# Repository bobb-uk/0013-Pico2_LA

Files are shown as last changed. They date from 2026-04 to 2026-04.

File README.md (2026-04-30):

# 0013-Pico2_LA
Logic analyser variant originally by El Gusman  https://github.com/gusmanb

Design errors:\
The M3 mounting holes have their PTH set at 3.0mm by mistake when it should be 3.2mm\
Pin1 on each of the three headers has it's solder mask opening a little too large.  It is possible to short the pin to GND when assembling.\
\
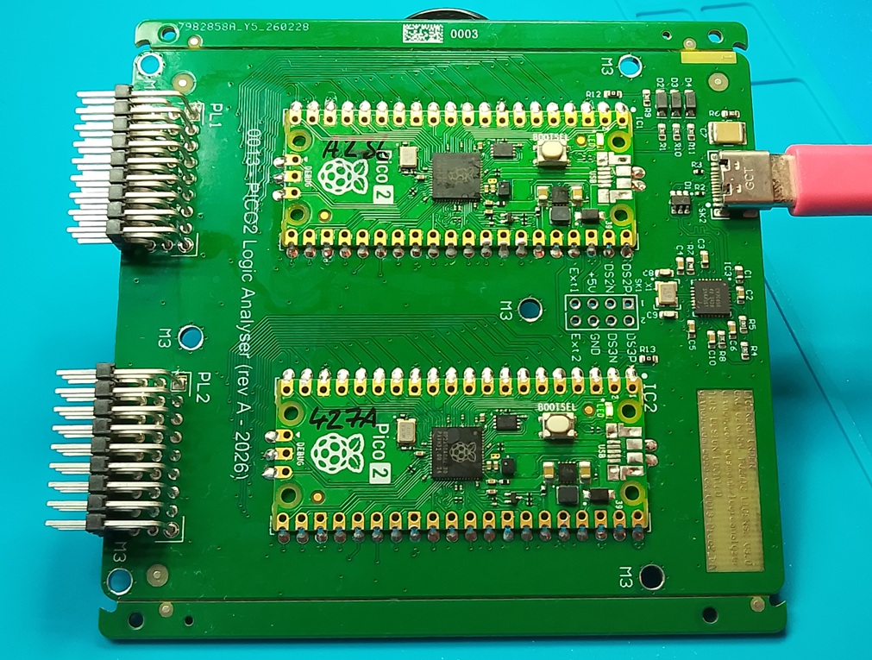
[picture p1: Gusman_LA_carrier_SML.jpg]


PL1 is the Master header.  PL2 is the 1st Slave header.

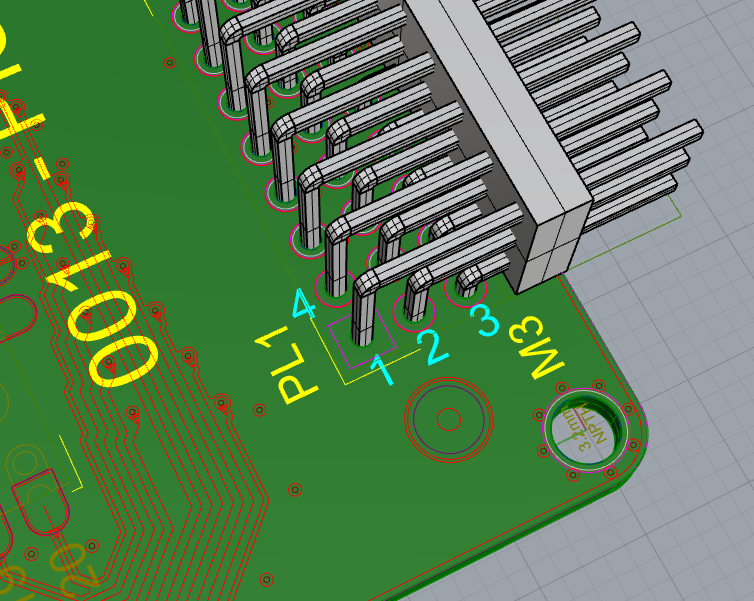
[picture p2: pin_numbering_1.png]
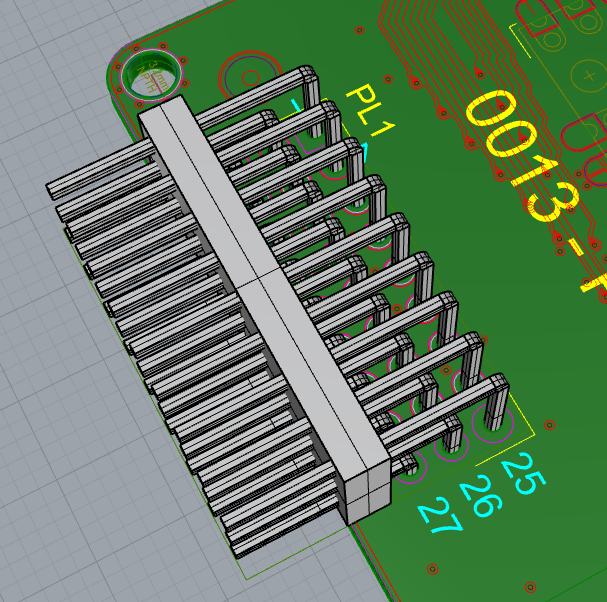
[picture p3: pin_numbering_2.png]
|  |  |
| --- | --- |
| When studying the schematic, make note of the pin numbering between the symbol and the footprint of PL1 & PL2. |

There will be a rev B of this design in the near future.\
The new revision will use programmable (with a capacitor) reset supervisor IC, so each of the PICO2 modules will have their nRESET inputs released in sequence upon power connected to the board.\
This will ensure the ttyACMx enumerations are in the sequence we want.\
Then we can assign ttyACM0 as the Master and ttyACM1 as the first Slave and know for certain that ttyACM0 references the Master pins on the signal headers.\
This saves having to use DMESG to look at which PICO2 was given which ttyACM port.

Head over to the Discussions tab if you want to make any comments.

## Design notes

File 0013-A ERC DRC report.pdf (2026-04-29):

## Electrical Rules Check Report

Class | Document | Message
Warning | Top.SchDoc | Nets Wire +5V has multiple names (Port +5V, Port VBUS, Power Object +5V (9), Power Object VBUS (3), Sheet Entry
| | PICO2-VBUS(Passive), Sheet Entry USB Hub-+5V(Passive))
Warning | Top.SchDoc | Nets Wire CHAN_0 has multiple names (Net Label CHAN_0 (4), Port CHANNELS.0 (2), Sheet Entry DIGITAL
| | IO-CHANNELS.0(Passive), Sheet Entry PICO2-CHANNELS.0(Passive))
Warning | Top.SchDoc | Nets Wire CHAN_1 has multiple names (Net Label CHAN_1 (4), Port CHANNELS.1 (2), Sheet Entry DIGITAL
| | IO-CHANNELS.1(Passive), Sheet Entry PICO2-CHANNELS.1(Passive))
Warning | Top.SchDoc | Nets Wire CHAN_2 has multiple names (Net Label CHAN_2 (4), Port CHANNELS.2 (2), Sheet Entry DIGITAL
| | IO-CHANNELS.2(Passive), Sheet Entry PICO2-CHANNELS.2(Passive))
Warning | Top.SchDoc | Nets Wire CHAN_3 has multiple names (Net Label CHAN_3 (4), Port CHANNELS.3 (2), Sheet Entry DIGITAL
| | IO-CHANNELS.3(Passive), Sheet Entry PICO2-CHANNELS.3(Passive))
Warning | Top.SchDoc | Nets Wire CHAN_4 has multiple names (Net Label CHAN_4 (4), Port CHANNELS.4 (2), Sheet Entry DIGITAL
| | IO-CHANNELS.4(Passive), Sheet Entry PICO2-CHANNELS.4(Passive))
Warning | Top.SchDoc | Nets Wire CHAN_5 has multiple names (Net Label CHAN_5 (4), Port CHANNELS.5 (2), Sheet Entry DIGITAL
| | IO-CHANNELS.5(Passive), Sheet Entry PICO2-CHANNELS.5(Passive))
Warning | Top.SchDoc | Nets Wire CHAN_6 has multiple names (Net Label CHAN_6 (4), Port CHANNELS.6 (2), Sheet Entry DIGITAL
| | IO-CHANNELS.6(Passive), Sheet Entry PICO2-CHANNELS.6(Passive))
Warning | Top.SchDoc | Nets Wire CHAN_7 has multiple names (Net Label CHAN_7 (4), Port CHANNELS.7 (2), Sheet Entry DIGITAL
| | IO-CHANNELS.7(Passive), Sheet Entry PICO2-CHANNELS.7(Passive))
Warning | Top.SchDoc | Nets Wire CHAN_8 has multiple names (Net Label CHAN_8 (4), Port CHANNELS.8 (2), Sheet Entry DIGITAL
| | IO-CHANNELS.8(Passive), Sheet Entry PICO2-CHANNELS.8(Passive))
Warning | Top.SchDoc | Nets Wire CHAN_9 has multiple names (Net Label CHAN_9 (4), Port CHANNELS.9 (2), Sheet Entry DIGITAL
| | IO-CHANNELS.9(Passive), Sheet Entry PICO2-CHANNELS.9(Passive))
Warning | Top.SchDoc | Nets Wire CHAN_10 has multiple names (Net Label CHAN_10 (4), Port CHANNELS.10 (2), Sheet Entry DIGITAL
| | IO-CHANNELS.10(Passive), Sheet Entry PICO2-CHANNELS.10(Passive))
Warning | Top.SchDoc | Nets Wire CHAN_11 has multiple names (Net Label CHAN_11 (4), Port CHANNELS.11 (2), Sheet Entry DIGITAL
| | IO-CHANNELS.11(Passive), Sheet Entry PICO2-CHANNELS.11(Passive))
Warning | Top.SchDoc | Nets Wire CHAN_12 has multiple names (Net Label CHAN_12 (4), Port CHANNELS.12 (2), Sheet Entry DIGITAL
| | IO-CHANNELS.12(Passive), Sheet Entry PICO2-CHANNELS.12(Passive))
Warning | Top.SchDoc | Nets Wire CHAN_13 has multiple names (Net Label CHAN_13 (4), Port CHANNELS.13 (2), Sheet Entry DIGITAL
| | IO-CHANNELS.13(Passive), Sheet Entry PICO2-CHANNELS.13(Passive))
Warning | Top.SchDoc | Nets Wire CHAN_14 has multiple names (Net Label CHAN_14 (4), Port CHANNELS.14 (2), Sheet Entry DIGITAL
| | IO-CHANNELS.14(Passive), Sheet Entry PICO2-CHANNELS.14(Passive))
Warning | Top.SchDoc | Nets Wire CHAN_15 has multiple names (Net Label CHAN_15 (4), Port CHANNELS.15 (2), Sheet Entry DIGITAL
| | IO-CHANNELS.15(Passive), Sheet Entry PICO2-CHANNELS.15(Passive))
Warning | Top.SchDoc | Nets Wire CHAN_16 has multiple names (Net Label CHAN_16 (4), Port CHANNELS.16 (2), Sheet Entry DIGITAL
| | IO-CHANNELS.16(Passive), Sheet Entry PICO2-CHANNELS.16(Passive))
Warning | Top.SchDoc | Nets Wire CHAN_17 has multiple names (Net Label CHAN_17 (4), Port CHANNELS.17 (2), Sheet Entry DIGITAL
| | IO-CHANNELS.17(Passive), Sheet Entry PICO2-CHANNELS.17(Passive))
Warning | Top.SchDoc | Nets Wire CHAN_18 has multiple names (Net Label CHAN_18 (4), Port CHANNELS.18 (2), Sheet Entry DIGITAL
| | IO-CHANNELS.18(Passive), Sheet Entry PICO2-CHANNELS.18(Passive))
Warning | Top.SchDoc | Nets Wire CHAN_19 has multiple names (Net Label CHAN_19 (4), Port CHANNELS.19 (2), Sheet Entry DIGITAL
| | IO-CHANNELS.19(Passive), Sheet Entry PICO2-CHANNELS.19(Passive))
Monday 2 Mar 2026 1:28:35 PM | Page 1 of 3

Class | Document | Message
Warning | Top.SchDoc | Nets Wire CHAN_20 has multiple names (Net Label CHAN_20 (4), Port CHANNELS.20 (2), Sheet Entry DIGITAL
| | IO-CHANNELS.20(Passive), Sheet Entry PICO2-CHANNELS.20(Passive))
Warning | Top.SchDoc | Nets Wire CHAN_21 has multiple names (Net Label CHAN_21 (4), Port CHANNELS.21 (2), Sheet Entry DIGITAL
| | IO-CHANNELS.21(Passive), Sheet Entry PICO2-CHANNELS.21(Passive))
Warning | Top.SchDoc | Nets Wire CHAN_22 has multiple names (Net Label CHAN_22 (4), Port CHANNELS.22 (2), Sheet Entry DIGITAL
| | IO-CHANNELS.22(Passive), Sheet Entry PICO2-CHANNELS.22(Passive))
Warning | Top.SchDoc | Nets Wire CHAN_23 has multiple names (Net Label CHAN_23 (4), Port CHANNELS.23 (2), Sheet Entry DIGITAL
| | IO-CHANNELS.23(Passive), Sheet Entry PICO2-CHANNELS.23(Passive))
Warning | Top.SchDoc | Nets Wire CHAN_24 has multiple names (Net Label CHAN_24 (4), Port CHANNELS.24 (2), Sheet Entry DIGITAL
| | IO-CHANNELS.24(Passive), Sheet Entry PICO2-CHANNELS.24(Passive))
Warning | Top.SchDoc | Nets Wire CHAN_25 has multiple names (Net Label CHAN_25 (4), Port CHANNELS.25 (2), Sheet Entry DIGITAL
| | IO-CHANNELS.25(Passive), Sheet Entry PICO2-CHANNELS.25(Passive))
Warning | Top.SchDoc | Nets Wire CHAN_26 has multiple names (Net Label CHAN_26 (4), Port CHANNELS.26 (2), Sheet Entry DIGITAL
| | IO-CHANNELS.26(Passive), Sheet Entry PICO2-CHANNELS.26(Passive))
Warning | Top.SchDoc | Nets Wire CHAN_27 has multiple names (Net Label CHAN_27 (4), Port CHANNELS.27 (2), Sheet Entry DIGITAL
| | IO-CHANNELS.27(Passive), Sheet Entry PICO2-CHANNELS.27(Passive))
Warning | Top.SchDoc | Nets Wire CHAN_28 has multiple names (Net Label CHAN_28 (4), Port CHANNELS.28 (2), Sheet Entry DIGITAL
| | IO-CHANNELS.28(Passive), Sheet Entry PICO2-CHANNELS.28(Passive))
Warning | Top.SchDoc | Nets Wire CHAN_29 has multiple names (Net Label CHAN_29 (4), Port CHANNELS.29 (2), Sheet Entry DIGITAL
| | IO-CHANNELS.29(Passive), Sheet Entry PICO2-CHANNELS.29(Passive))
Warning | Top.SchDoc | Nets Wire CHAN_30 has multiple names (Net Label CHAN_30 (4), Port CHANNELS.30 (2), Sheet Entry DIGITAL
| | IO-CHANNELS.30(Passive), Sheet Entry PICO2-CHANNELS.30(Passive))
Warning | Top.SchDoc | Nets Wire CHAN_31 has multiple names (Net Label CHAN_31 (4), Port CHANNELS.31 (2), Sheet Entry DIGITAL
| | IO-CHANNELS.31(Passive), Sheet Entry PICO2-CHANNELS.31(Passive))
Warning | Top.SchDoc | Nets Wire CHAN_32 has multiple names (Net Label CHAN_32 (4), Port CHANNELS.32 (2), Sheet Entry DIGITAL
| | IO-CHANNELS.32(Passive), Sheet Entry PICO2-CHANNELS.32(Passive))
Warning | Top.SchDoc | Nets Wire CHAN_33 has multiple names (Net Label CHAN_33 (4), Port CHANNELS.33 (2), Sheet Entry DIGITAL
| | IO-CHANNELS.33(Passive), Sheet Entry PICO2-CHANNELS.33(Passive))
Warning | Top.SchDoc | Nets Wire CHAN_34 has multiple names (Net Label CHAN_34 (4), Port CHANNELS.34 (2), Sheet Entry DIGITAL
| | IO-CHANNELS.34(Passive), Sheet Entry PICO2-CHANNELS.34(Passive))
Warning | Top.SchDoc | Nets Wire CHAN_35 has multiple names (Net Label CHAN_35 (4), Port CHANNELS.35 (2), Sheet Entry DIGITAL
| | IO-CHANNELS.35(Passive), Sheet Entry PICO2-CHANNELS.35(Passive))
Warning | Top.SchDoc | Nets Wire CHAN_36 has multiple names (Net Label CHAN_36 (4), Port CHANNELS.36 (2), Sheet Entry DIGITAL
| | IO-CHANNELS.36(Passive), Sheet Entry PICO2-CHANNELS.36(Passive))
Warning | Top.SchDoc | Nets Wire CHAN_37 has multiple names (Net Label CHAN_37 (4), Port CHANNELS.37 (2), Sheet Entry DIGITAL
| | IO-CHANNELS.37(Passive), Sheet Entry PICO2-CHANNELS.37(Passive))
Warning | Top.SchDoc | Nets Wire CHAN_38 has multiple names (Net Label CHAN_38 (4), Port CHANNELS.38 (2), Sheet Entry DIGITAL
| | IO-CHANNELS.38(Passive), Sheet Entry PICO2-CHANNELS.38(Passive))
Warning | Top.SchDoc | Nets Wire CHAN_39 has multiple names (Net Label CHAN_39 (4), Port CHANNELS.39 (2), Sheet Entry DIGITAL
| | IO-CHANNELS.39(Passive), Sheet Entry PICO2-CHANNELS.39(Passive))
Warning | Top.SchDoc | Nets Wire CHAN_40 has multiple names (Net Label CHAN_40 (4), Port CHANNELS.40 (2), Sheet Entry DIGITAL
| | IO-CHANNELS.40(Passive), Sheet Entry PICO2-CHANNELS.40(Passive))
Warning | Top.SchDoc | Nets Wire CHAN_41 has multiple names (Net Label CHAN_41 (4), Port CHANNELS.41 (2), Sheet Entry DIGITAL
| | IO-CHANNELS.41(Passive), Sheet Entry PICO2-CHANNELS.41(Passive))
Warning | Top.SchDoc | Nets Wire CHAN_42 has multiple names (Net Label CHAN_42 (4), Port CHANNELS.42 (2), Sheet Entry DIGITAL
Monday 2 Mar 2026 1:28:35 PM | Page 2 of 3

Class | Document | Message
| | IO-CHANNELS.42(Passive), Sheet Entry PICO2-CHANNELS.42(Passive))
Warning | Top.SchDoc | Nets Wire CHAN_43 has multiple names (Net Label CHAN_43 (4), Port CHANNELS.43 (2), Sheet Entry DIGITAL
| | IO-CHANNELS.43(Passive), Sheet Entry PICO2-CHANNELS.43(Passive))
Warning | Top.SchDoc | Nets Wire CHAN_44 has multiple names (Net Label CHAN_44 (4), Port CHANNELS.44 (2), Sheet Entry DIGITAL
| | IO-CHANNELS.44(Passive), Sheet Entry PICO2-CHANNELS.44(Passive))
Warning | Top.SchDoc | Nets Wire CHAN_45 has multiple names (Net Label CHAN_45 (4), Port CHANNELS.45 (2), Sheet Entry DIGITAL
| | IO-CHANNELS.45(Passive), Sheet Entry PICO2-CHANNELS.45(Passive))
Warning | Top.SchDoc | Nets Wire CHAN_46 has multiple names (Net Label CHAN_46 (4), Port CHANNELS.46 (2), Sheet Entry DIGITAL
| | IO-CHANNELS.46(Passive), Sheet Entry PICO2-CHANNELS.46(Passive))
Warning | Top.SchDoc | Nets Wire CHAN_47 has multiple names (Net Label CHAN_47 (4), Port CHANNELS.47 (2), Sheet Entry DIGITAL
| | IO-CHANNELS.47(Passive), Sheet Entry PICO2-CHANNELS.47(Passive))
Warning | Top.SchDoc | Nets Wire DS1_N has multiple names (Net Label DS1_N, Net Label USB1_N (2), Port USB DS Ports.DS_1_N, Port USB.USB1_N,
| | Sheet Entry PICO2-USB.USB1_N(Passive), Sheet Entry USB Hub-USB DS Ports.DS_1_N(Passive))
Warning | Top.SchDoc | Nets Wire DS1_P has multiple names (Net Label DS1_P, Net Label USB1_P (2), Port USB DS Ports.DS_1_P, Port USB.USB1_P,
| | Sheet Entry PICO2-USB.USB1_P(Passive), Sheet Entry USB Hub-USB DS Ports.DS_1_P(Passive))
Warning | Top.SchDoc | Nets Wire DS2_N has multiple names (Net Label DS2_N, Port USB DS Ports.DS_2_N, Sheet Entry USB Hub-USB DS
| | Ports.DS_2_N(Passiv e))
Warning | Top.SchDoc | Nets Wire DS2_P has multiple names (Net Label DS2_P, Port USB DS Ports.DS_2_P, Sheet Entry USB Hub-USB DS
| | Ports.DS_2_P(Passiv e))
Warning | Top.SchDoc | Nets Wire DS3_N has multiple names (Net Label DS3_N, Port USB DS Ports.DS_3_N, Sheet Entry USB Hub-USB DS
| | Ports.DS_3_N(Passiv e))
Warning | Top.SchDoc | Nets Wire DS3_P has multiple names (Net Label DS3_P, Port USB DS Ports.DS_3_P, Sheet Entry USB Hub-USB DS
| | Ports.DS_3_P(Passiv e))
Warning | Top.SchDoc | Nets Wire DS4_N has multiple names (Net Label DS4_N, Net Label USB2_N (2), Port USB DS Ports.DS_4_N, Port USB.USB2_N,
| | Sheet Entry PICO2-USB.USB2_N(Passive), Sheet Entry USB Hub-USB DS Ports.DS_4_N(Passive))
Warning | Top.SchDoc | Nets Wire DS4_P has multiple names (Net Label DS4_P, Net Label USB2_P (2), Port USB DS Ports.DS_4_P, Port USB.USB2_P,
| | Sheet Entry PICO2-USB.USB2_P(Passive), Sheet Entry USB Hub-USB DS Ports.DS_4_P(Passive))
Warning | Top.SchDoc | Nets Wire ExtTrig1 has multiple names (Net Label ExtTrig1, Net Label TrigS1 (2), Port ExtTrig1, Sheet Entry PICO2-ExtTrig1(Passive))
Warning | Top.SchDoc | Nets Wire ExtTrig2 has multiple names (Net Label ExtTrig2, Net Label TrigS2 (2), Port ExtTrig2, Sheet Entry PICO2-ExtTrig2(Passive))
Monday 2 Mar 2026 1:28:35 PM | Page 3 of 3

## Design Rules Verification Report

Filename : Z:\Altium\0013 - 48ch PICO2 LA\175-00334-B.PcbDoc | Warnings 0

## Rule Violations 0 Waived Violations 48

Warnings
Total | 0
Monday 2 Mar 2026 1:28:46 PM | Page 1 of 5

Rule Violations
Clearance Constraint (Gap=0.125mm) (All),(All)

0
Short-Circuit Constraint (Allowed=No) (All),(All)

0
Un-Routed Net Constraint ( (All) )

0
Modified Polygon (Allow modified: No), (Allow shelved: No)

0
Width Constraint (Min=0.15mm) (Max=10mm) (Preferred=0.15mm) (All)

0
Minimum Annular Ring (Minimum=0.15mm) (((ObjectKind = 'Pad') OR (ObjectKind = 'Via')) And (Layer = 'MultiLayer')

0
Minimum Annular Ring (Minimum=0.175mm) (((ObjectKind = 'Pad') OR (ObjectKind = 'Via')) And (Layer = 'MultiLayer')

0
Hole Size Constraint (Min=0.25mm) (Max=6mm) (All)

0
Hole To Hole Clearance (Gap=0.2mm) (IsVia),(IsVia)

0
Hole To Hole Clearance (Gap=0.45mm) (All),(All)

0
Minimum Solder Mask Sliver (Gap=0.1mm) (All),(not ( HasFootprint('Cypress QFN50P500X500X80_HS-29N') or

0
Silk To Solder Mask (Clearance=0.2mm) (IsPad),(All)

0
Silk to Silk (Clearance=0.2mm) (All),(All)

0
Net Antennae (Tolerance=0mm) (All)

0
Board Clearance Constraint (Gap=0mm) (All)

0
Length Constraint (Min=66.1mm) (Max=66.3mm) (InNet('CHAN_12'))

0
Length Constraint (Min=67.5mm) (Max=67.7mm) (InNet('CHAN_15'))

0
Length Constraint (Min=63.4mm) (Max=63.6mm) (InNet('CHAN_13'))

0
Length Constraint (Min=64.8mm) (Max=65mm) (InNet('CHAN_14'))

0
Length Constraint (Min=79.3mm) (Max=79.5mm) (InNet('CHAN_4'))

0
Length Constraint (Min=81.3mm) (Max=81.5mm) (InNet('CHAN_22'))

0
Length Constraint (Min=78.9mm) (Max=79.1mm) (InNet('CHAN_8'))

0
Length Constraint (Min=79.1mm) (Max=79.3mm) (InNet('CHAN_19'))

0
Length Constraint (Min=81.5mm) (Max=81.7mm) (InNet('CHAN_5'))

0
Length Constraint (Min=82.2mm) (Max=82.4mm) (InNet('CHAN_21'))

0
Length Constraint (Min=82mm) (Max=82.2mm) (InNet('CHAN_7'))

0
Length Constraint (Min=81.9mm) (Max=82.1mm) (InNet('CHAN_20'))

0
Length Constraint (Min=82.1mm) (Max=82.3mm) (InNet('CHAN_6'))

0
Length Constraint (Min=77mm) (Max=77.2mm) (InNet('CHAN_18'))

0
Length Constraint (Min=72.7mm) (Max=72.9mm) (InNet('CHAN_16'))

0
Length Constraint (Min=74.6mm) (Max=74.8mm) (InNet('CHAN_3'))

0
Length Constraint (Min=72.5mm) (Max=72.7mm) (InNet('CHAN_2'))

0
Length Constraint (Min=71.3mm) (Max=71.5mm) (InNet('CHAN_11'))

0
Length Constraint (Min=71mm) (Max=71.2mm) (InNet('CHAN_1'))

0
Length Constraint (Min=76.8mm) (Max=77mm) (InNet('CHAN_9'))

0
Length Constraint (Min=76.7mm) (Max=76.9mm) (InNet('CHAN_23'))

0

Monday 2 Mar 2026 1:28:46 PM | Page 2 of 5

Rule Violations
Length Constraint (Min=74.8mm) (Max=75mm) (InNet('CHAN_17')) | 0
Length Constraint (Min=74mm) (Max=74.2mm) (InNet('CHAN_10')) | 0
Height Constraint (Min=0mm) (Max=25mm) (Prefered=12.5mm) (All) | 0
Silk primitive without silk layer | 0
Total | 0

Waived Violations
Hole To Hole Clearance (Gap=0.45mm) (All),(All) | 48
Total | 48
Monday 2 Mar 2026 1:28:46 PM | Page 3 of 5

Hole To Hole Clearance (Gap=0.45mm) (All),(All)
Hole To Hole Clearance Constraint: (0.441mm < 0.45mm) Between Pad FH1-1(0mm,71.8mm) on Multi-Layer And Via (0mm,69.734mm) from L1 to L4 Waived by Robert Beattie at 25/02/2026 20:04:23 Hole To Hole Clearance Constraint: (0.441mm < 0.45mm) Between Pad FH1-1(0mm,71.8mm) on Multi-Layer And Via (0mm,73.866mm) from L1 to L4 Waived by Robert Beattie at 25/02/2026 20:04:23 Hole To Hole Clearance Constraint: (0.441mm < 0.45mm) Between Pad FH1-1(0mm,71.8mm) on Multi-Layer And Via (1.461mm,70.339mm) from L1 to L4 Waived by Robert Beattie at 25/02/2026 20:04:23 Hole To Hole Clearance Constraint: (0.441mm < 0.45mm) Between Pad FH1-1(0mm,71.8mm) on Multi-Layer And Via (-1.461mm,70.339mm) from L1 to L4 Waived by Robert Beattie at 25/02/2026 20:04:23 Hole To Hole Clearance Constraint: (0.441mm < 0.45mm) Between Pad FH1-1(0mm,71.8mm) on Multi-Layer And Via (1.461mm,73.261mm) from L1 to L4 Waived by Robert Beattie at 25/02/2026 20:04:23 Hole To Hole Clearance Constraint: (0.441mm < 0.45mm) Between Pad FH1-1(0mm,71.8mm) on Multi-Layer And Via (-1.461mm,73.261mm) from L1 to L4 Waived by Robert Beattie at 25/02/2026 20:04:23 Hole To Hole Clearance Constraint: (0.441mm < 0.45mm) Between Pad FH1-1(0mm,71.8mm) on Multi-Layer And Via (2.066mm,71.8mm) from L1 to L4 Waived by Robert Beattie at 25/02/2026 20:04:23 Hole To Hole Clearance Constraint: (0.441mm < 0.45mm) Between Pad FH1-1(0mm,71.8mm) on Multi-Layer And Via (-2.066mm,71.8mm) from L1 to L4 Waived by Robert Beattie at 25/02/2026 20:04:23 Hole To Hole Clearance Constraint: (0.441mm < 0.45mm) Between Pad FH2-1(0mm,0mm) on Multi-Layer And Via (0mm,2.066mm) from L1 to L4 Waived by Robert Beattie at 25/02/2026 20:04:23
Hole To Hole Clearance Constraint: (0.441mm < 0.45mm) Between Pad FH2-1(0mm,0mm) on Multi-Layer And Via (0mm,-2.066mm) from L1 to L4 Waived by Robert Beattie at 25/02/2026 20:04:23 Hole To Hole Clearance Constraint: (0.441mm < 0.45mm) Between Pad FH2-1(0mm,0mm) on Multi-Layer And Via (1.461mm,1.461mm) from L1 to L4 Waived by Robert Beattie at 25/02/2026 20:04:23 Hole To Hole Clearance Constraint: (0.441mm < 0.45mm) Between Pad FH2-1(0mm,0mm) on Multi-Layer And Via (1.461mm,-1.461mm) from L1 to L4 Waived by Robert Beattie at 25/02/2026 20:04:23 Hole To Hole Clearance Constraint: (0.441mm < 0.45mm) Between Pad FH2-1(0mm,0mm) on Multi-Layer And Via (-1.461mm,1.461mm) from L1 to L4 Waived by Robert Beattie at 25/02/2026 20:04:23 Hole To Hole Clearance Constraint: (0.441mm < 0.45mm) Between Pad FH2-1(0mm,0mm) on Multi-Layer And Via (-1.461mm,-1.461mm) from L1 to L4 Waived by Robert Beattie at 25/02/2026 20:04:23 Hole To Hole Clearance Constraint: (0.441mm < 0.45mm) Between Pad FH2-1(0mm,0mm) on Multi-Layer And Via (2.066mm,0mm) from L1 to L4 Waived by Robert Beattie at 25/02/2026 20:04:23
Hole To Hole Clearance Constraint: (0.441mm < 0.45mm) Between Pad FH2-1(0mm,0mm) on Multi-Layer And Via (-2.066mm,0mm) from L1 to L4 Waived by Robert Beattie at 25/02/2026 20:04:23
Hole To Hole Clearance Constraint: (0.441mm < 0.45mm) Between Pad FH3-1(75.8mm,0mm) on Multi-Layer And Via (73.734mm,0mm) from L1 to L4 Waived by Robert Beattie at 25/02/2026 20:04:23 Hole To Hole Clearance Constraint: (0.441mm < 0.45mm) Between Pad FH3-1(75.8mm,0mm) on Multi-Layer And Via (74.339mm,1.461mm) from L1 to L4 Waived by Robert Beattie at 25/02/2026 20:04:23 Hole To Hole Clearance Constraint: (0.441mm < 0.45mm) Between Pad FH3-1(75.8mm,0mm) on Multi-Layer And Via (74.339mm,-1.461mm) from L1 to L4 Waived by Robert Beattie at 25/02/2026 20:04:23 Hole To Hole Clearance Constraint: (0.441mm < 0.45mm) Between Pad FH3-1(75.8mm,0mm) on Multi-Layer And Via (75.8mm,2.066mm) from L1 to L4 Waived by Robert Beattie at 25/02/2026 20:04:23 Hole To Hole Clearance Constraint: (0.441mm < 0.45mm) Between Pad FH3-1(75.8mm,0mm) on Multi-Layer And Via (75.8mm,-2.066mm) from L1 to L4 Waived by Robert Beattie at 25/02/2026 20:04:23 Hole To Hole Clearance Constraint: (0.441mm < 0.45mm) Between Pad FH3-1(75.8mm,0mm) on Multi-Layer And Via (77.261mm,1.461mm) from L1 to L4 Waived by Robert Beattie at 25/02/2026 20:04:23 Hole To Hole Clearance Constraint: (0.441mm < 0.45mm) Between Pad FH3-1(75.8mm,0mm) on Multi-Layer And Via (77.261mm,-1.461mm) from L1 to L4 Waived by Robert Beattie at 25/02/2026 20:04:23 Hole To Hole Clearance Constraint: (0.441mm < 0.45mm) Between Pad FH3-1(75.8mm,0mm) on Multi-Layer And Via (77.866mm,0mm) from L1 to L4 Waived by Robert Beattie at 25/02/2026 20:04:23
Hole To Hole Clearance Constraint: (0.441mm < 0.45mm) Between Pad FH4-1(75.8mm,71.8mm) on Multi-Layer And Via (73.734mm,71.8mm) from L1 to L4 Waived by Robert Beattie at 25/02/2026 20:04:23 Hole To Hole Clearance Constraint: (0.441mm < 0.45mm) Between Pad FH4-1(75.8mm,71.8mm) on Multi-Layer And Via (74.339mm,70.339mm) from L1 to L4 Waived by Robert Beattie at 25/02/2026 20:04:23 Hole To Hole Clearance Constraint: (0.441mm < 0.45mm) Between Pad FH4-1(75.8mm,71.8mm) on Multi-Layer And Via (74.339mm,73.261mm) from L1 to L4 Waived by Robert Beattie at 25/02/2026 20:04:23 Hole To Hole Clearance Constraint: (0.441mm < 0.45mm) Between Pad FH4-1(75.8mm,71.8mm) on Multi-Layer And Via (75.8mm,69.734mm) from L1 to L4 Waived by Robert Beattie at 25/02/2026 20:04:23 Hole To Hole Clearance Constraint: (0.441mm < 0.45mm) Between Pad FH4-1(75.8mm,71.8mm) on Multi-Layer And Via (75.8mm,73.866mm) from L1 to L4 Waived by Robert Beattie at 25/02/2026 20:04:23 Hole To Hole Clearance Constraint: (0.441mm < 0.45mm) Between Pad FH4-1(75.8mm,71.8mm) on Multi-Layer And Via (77.261mm,70.339mm) from L1 to L4 Waived by Robert Beattie at 25/02/2026 20:04:23 Hole To Hole Clearance Constraint: (0.441mm < 0.45mm) Between Pad FH4-1(75.8mm,71.8mm) on Multi-Layer And Via (77.261mm,73.261mm) from L1 to L4 Waived by Robert Beattie at 25/02/2026 20:04:23 Hole To Hole Clearance Constraint: (0.441mm < 0.45mm) Between Pad FH4-1(75.8mm,71.8mm) on Multi-Layer And Via (77.866mm,71.8mm) from L1 to L4 Waived by Robert Beattie at 25/02/2026 20:04:23 Hole To Hole Clearance Constraint: (0.441mm < 0.45mm) Between Pad FH5-1(38mm,56mm) on Multi-Layer And Via (35.934mm,56mm) from L1 to L4 Waived by Robert Beattie at 25/02/2026 20:04:23
Hole To Hole Clearance Constraint: (0.441mm < 0.45mm) Between Pad FH5-1(38mm,56mm) on Multi-Layer And Via (36.539mm,54.539mm) from L1 to L4 Waived by Robert Beattie at 25/02/2026 20:04:23 Hole To Hole Clearance Constraint: (0.441mm < 0.45mm) Between Pad FH5-1(38mm,56mm) on Multi-Layer And Via (36.539mm,57.461mm) from L1 to L4 Waived by Robert Beattie at 25/02/2026 20:04:23
Hole To Hole Clearance Constraint: (0.441mm < 0.45mm) Between Pad FH5-1(38mm,56mm) on Multi-Layer And Via (38mm,53.934mm) from L1 to L4 Waived by Robert Beattie at 25/02/2026 20:04:23
Monday 2 Mar 2026 1:28:46 PM | Page 4 of 5

Hole To Hole Clearance (Gap=0.45mm) (All),(All)
Hole To Hole Clearance Constraint: (0.441mm < 0.45mm) Between Pad FH5-1(38mm,56mm) on Multi-Layer And Via (38mm,58.066mm) from L1 to L4 Waived by Robert Beattie at 25/02/2026 20:04:23 Hole To Hole Clearance Constraint: (0.441mm < 0.45mm) Between Pad FH5-1(38mm,56mm) on Multi-Layer And Via (39.461mm,54.539mm) from L1 to L4 Waived by Robert Beattie at 25/02/2026 20:04:23 Hole To Hole Clearance Constraint: (0.441mm < 0.45mm) Between Pad FH5-1(38mm,56mm) on Multi-Layer And Via (39.461mm,57.461mm) from L1 to L4 Waived by Robert Beattie at 25/02/2026 20:04:23 Hole To Hole Clearance Constraint: (0.441mm < 0.45mm) Between Pad FH5-1(38mm,56mm) on Multi-Layer And Via (40.066mm,56mm) from L1 to L4 Waived by Robert Beattie at 25/02/2026 20:04:23 Hole To Hole Clearance Constraint: (0.441mm < 0.45mm) Between Pad FH6-1(42mm,8mm) on Multi-Layer And Via (39.934mm,8mm) from L1 to L4 Waived by Robert Beattie at 25/02/2026 20:04:23
Hole To Hole Clearance Constraint: (0.441mm < 0.45mm) Between Pad FH6-1(42mm,8mm) on Multi-Layer And Via (40.539mm,6.539mm) from L1 to L4 Waived by Robert Beattie at 25/02/2026 20:04:23 Hole To Hole Clearance Constraint: (0.441mm < 0.45mm) Between Pad FH6-1(42mm,8mm) on Multi-Layer And Via (40.539mm,9.461mm) from L1 to L4 Waived by Robert Beattie at 25/02/2026 20:04:23 Hole To Hole Clearance Constraint: (0.441mm < 0.45mm) Between Pad FH6-1(42mm,8mm) on Multi-Layer And Via (42mm,10.066mm) from L1 to L4 Waived by Robert Beattie at 25/02/2026 20:04:23 Hole To Hole Clearance Constraint: (0.441mm < 0.45mm) Between Pad FH6-1(42mm,8mm) on Multi-Layer And Via (42mm,5.934mm) from L1 to L4 Waived by Robert Beattie at 25/02/2026 20:04:23 Hole To Hole Clearance Constraint: (0.441mm < 0.45mm) Between Pad FH6-1(42mm,8mm) on Multi-Layer And Via (43.461mm,6.539mm) from L1 to L4 Waived by Robert Beattie at 25/02/2026 20:04:23 Hole To Hole Clearance Constraint: (0.441mm < 0.45mm) Between Pad FH6-1(42mm,8mm) on Multi-Layer And Via (43.461mm,9.461mm) from L1 to L4 Waived by Robert Beattie at 25/02/2026 20:04:23 Hole To Hole Clearance Constraint: (0.441mm < 0.45mm) Between Pad FH6-1(42mm,8mm) on Multi-Layer And Via (44.066mm,8mm) from L1 to L4 Waived by Robert Beattie at 25/02/2026 20:04:23
Monday 2 Mar 2026 1:28:46 PM | Page 5 of 5

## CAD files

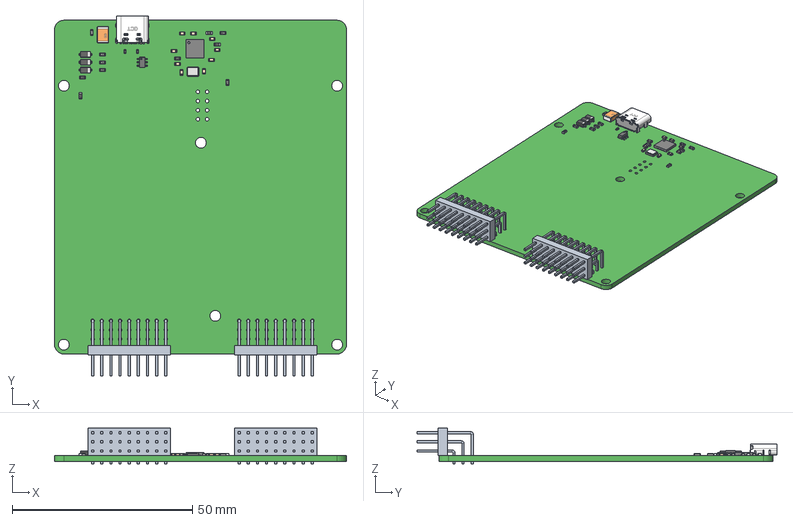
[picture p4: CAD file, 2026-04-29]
0013-A STEP.step
81.0 x 99.8 x 9.91 mm
RES-0603 x 11
SOD123-DEFAULT x 3
RES-0402 x 2
SOT23-6-2
CAP-0603 x 9
1812 SMD Capacitor
Xtal-3225
USB4105-GF-A-120_PART1
USB4105-GF-A-120_PART2
Thermal Shape
Samtec TSW-110-08-T-T-RA x 2

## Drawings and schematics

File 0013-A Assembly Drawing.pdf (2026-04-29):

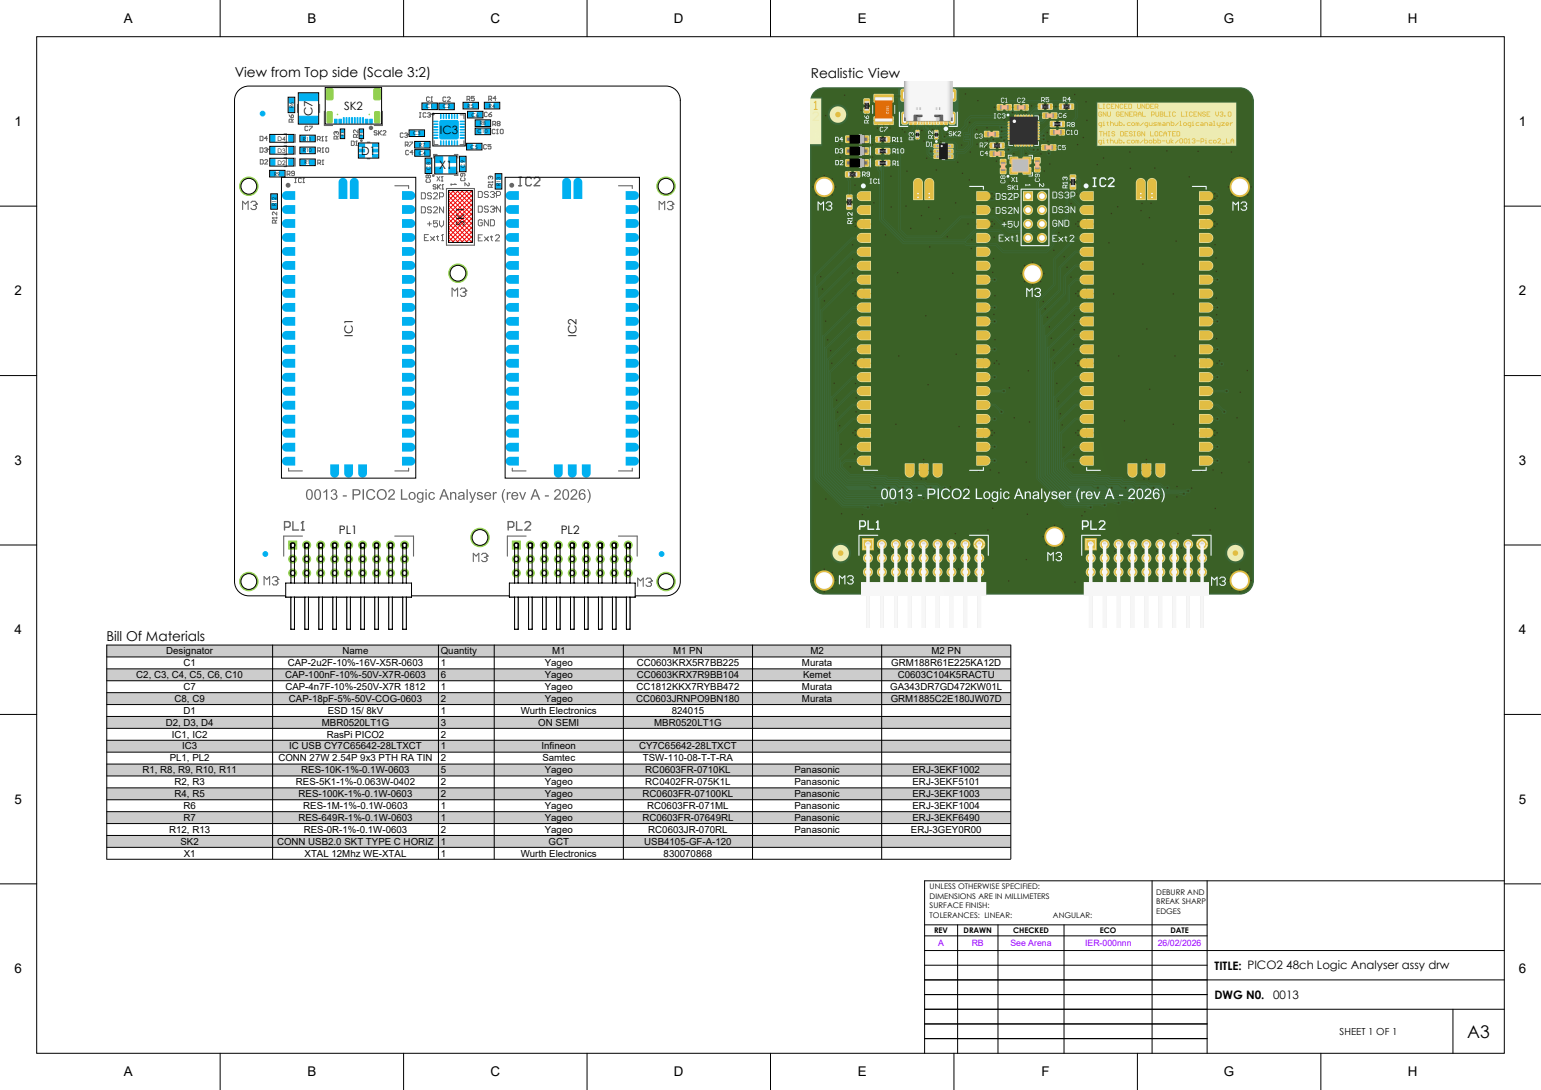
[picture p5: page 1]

Designator | Name | Quantity | M1 | M1 PN | M2 | M2 PN
C1 | CAP-2u2F-10%-16V-X5R-0603 | 1 | Yageo | CC0603KRX5R7BB225 | Murata | GRM188R61E225KA12D

C2, C3, C4, C5, C6, C10 | CAP-100nF-10%-50V-X7R-0603 | 6 | Yageo | CC0603KRX7R9BB104 | Kemet | C0603C104K5RACTU

C7 | CAP-4n7F-10%-250V-X7R 1812 | 1 | Yageo | CC1812KKX7RYBB472 | Murata | GA343DR7GD472KW01L
C8, C9 | CAP-18pF-5%-50V-COG-0603 | 2 | Yageo | CC0603JRNPO9BN180 | Murata | GRM1885C2E180JW07D
D1 | ESD 15/ 8kV | 1 | Wurth Electronics | 824015
D2, D3, D4 | MBR0520LT1G | 3 | ON SEMI | MBR0520LT1G
IC1, IC2 | RasPi PICO2 | 2
IC3 | IC USB CY7C65642-28LTXCT | 1 | Infineon | CY7C65642-28LTXCT
PL1, PL2 | CONN 27W 2.54P 9x3 PTH RA TIN | 2 | Samtec | TSW-110-08-T-T-RA
R1, R8, R9, R10, R11 | RES-10K-1%-0.1W-0603 | 5 | Yageo | RC0603FR-0710KL | Panasonic | ERJ-3EKF1002
R2, R3 | RES-5K1-1%-0.063W-0402 | 2 | Yageo | RC0402FR-075K1L | Panasonic | ERJ-3EKF5101
R4, R5 | RES-100K-1%-0.1W-0603 | 2 | Yageo | RC0603FR-07100KL | Panasonic | ERJ-3EKF1003
R6 | RES-1M-1%-0.1W-0603 | 1 | Yageo | RC0603FR-071ML | Panasonic | ERJ-3EKF1004
R7 | RES-649R-1%-0.1W-0603 | 1 | Yageo | RC0603FR-07649RL | Panasonic | ERJ-3EKF6490
R12, R13 | RES-0R-1%-0.1W-0603 | 2 | Yageo | RC0603JR-070RL | Panasonic | ERJ-3GEY0R00
SK2 | CONN USB2.0 SKT TYPE C HORIZ | 1 | GCT | USB4105-GF-A-120
X1 | XTAL 12Mhz WE-XTAL | 1 | Wurth Electronics | 830070868

UNLESS OTHERWISE SPECIFIED:
DIMENSIONS ARE IN MILLIMETERS
SURFACE FINISH:

REV | DRAWN | CHECKED | ECO | DATE
A | RB | See Arena | IER-000nnn | 26/02/2026

TITLE:
PICO2 48ch Logic Analyser assy drw

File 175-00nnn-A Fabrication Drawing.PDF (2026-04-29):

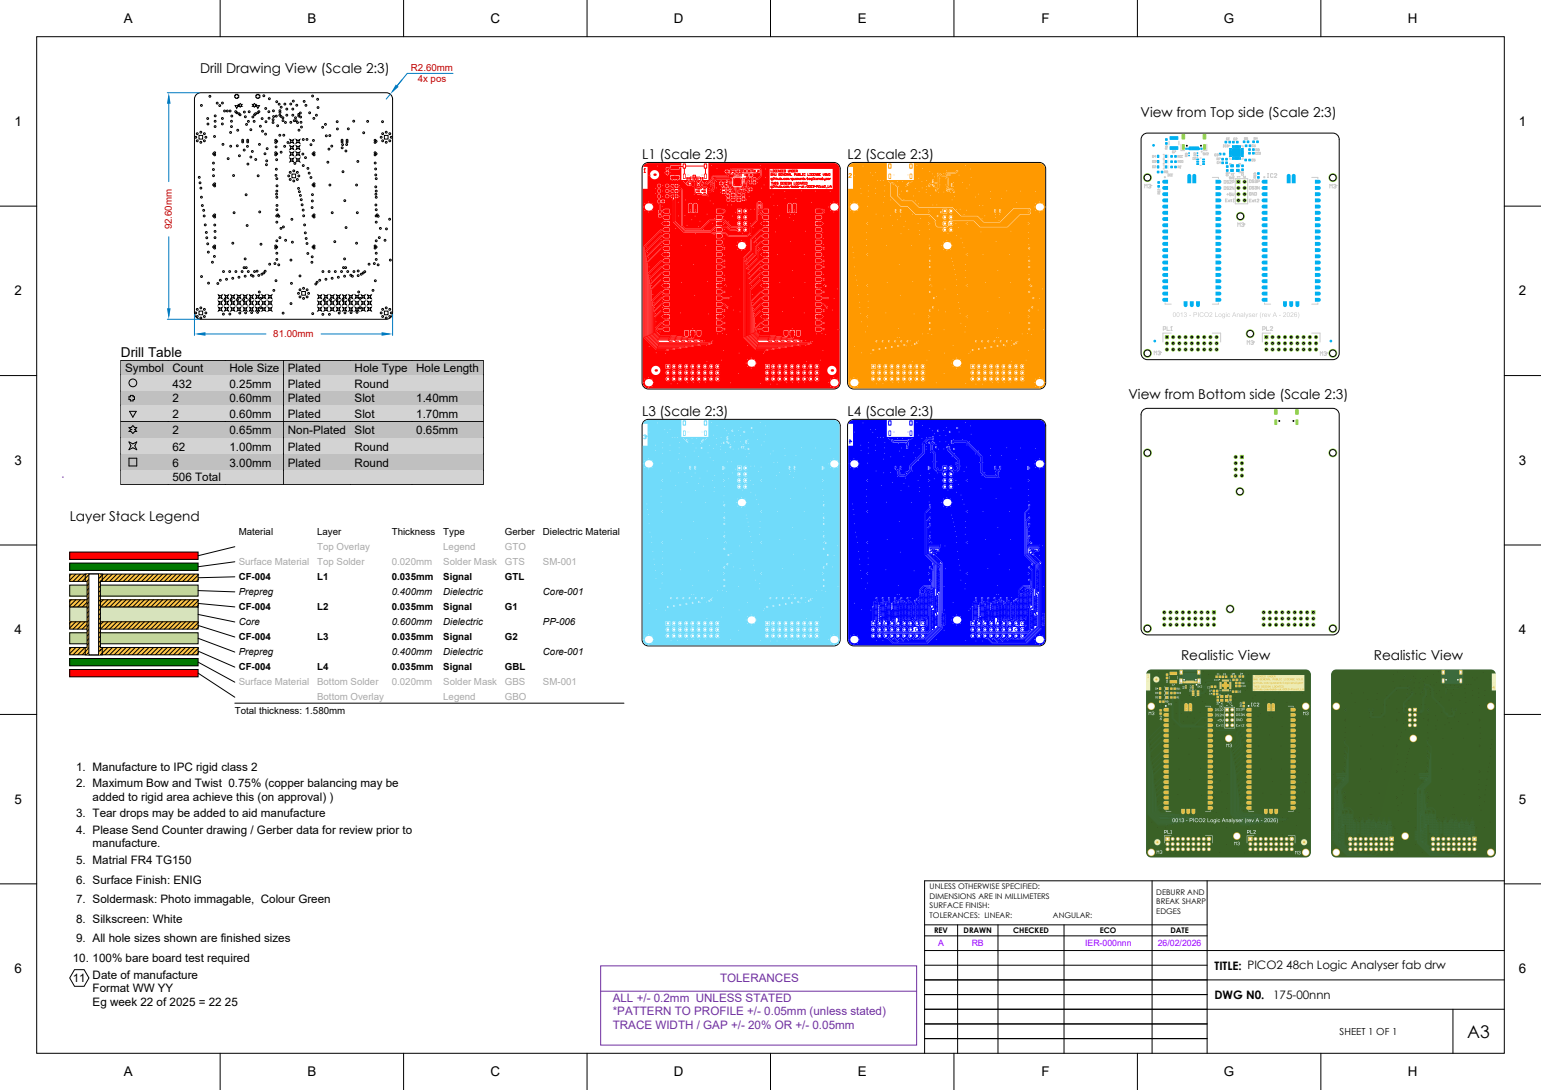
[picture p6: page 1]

Drill Drawing View (Scale 2:3)

View from Top side (Scale 2:3)

View from Bottom side (Scale 2:3)

1. Manufacture to IPC rigid class 2
Maximum Bow and Twist 0.75% (copper balancing may be
added to rigid area achieve this (on approval) )
3. Tear drops may be added to aid manufacture
Please Send Counter drawing / Gerber data for review prior to
manufacture.
5. Matrial FR4 TG150
6. Surface Finish: ENIG
7. Soldermask: Photo immagable, Colour Green
8. Silkscreen: White
9. All hole sizes shown are finished sizes
10. 100% bare board test required
Date of manufacture
Format WW YY
Eg week 22 of 2025 = 22 25

UNLESS OTHERWISE SPECIFIED:
DIMENSIONS ARE IN MILLIMETERS
SURFACE FINISH:
REV

TITLE:
PICO2 48ch Logic Analyser fab drw

ALL +/- 0.2mm UNLESS STATED
*PATTERN TO PROFILE +/- 0.05mm (unless stated)
TRACE WIDTH / GAP +/- 20% OR +/- 0.05mm

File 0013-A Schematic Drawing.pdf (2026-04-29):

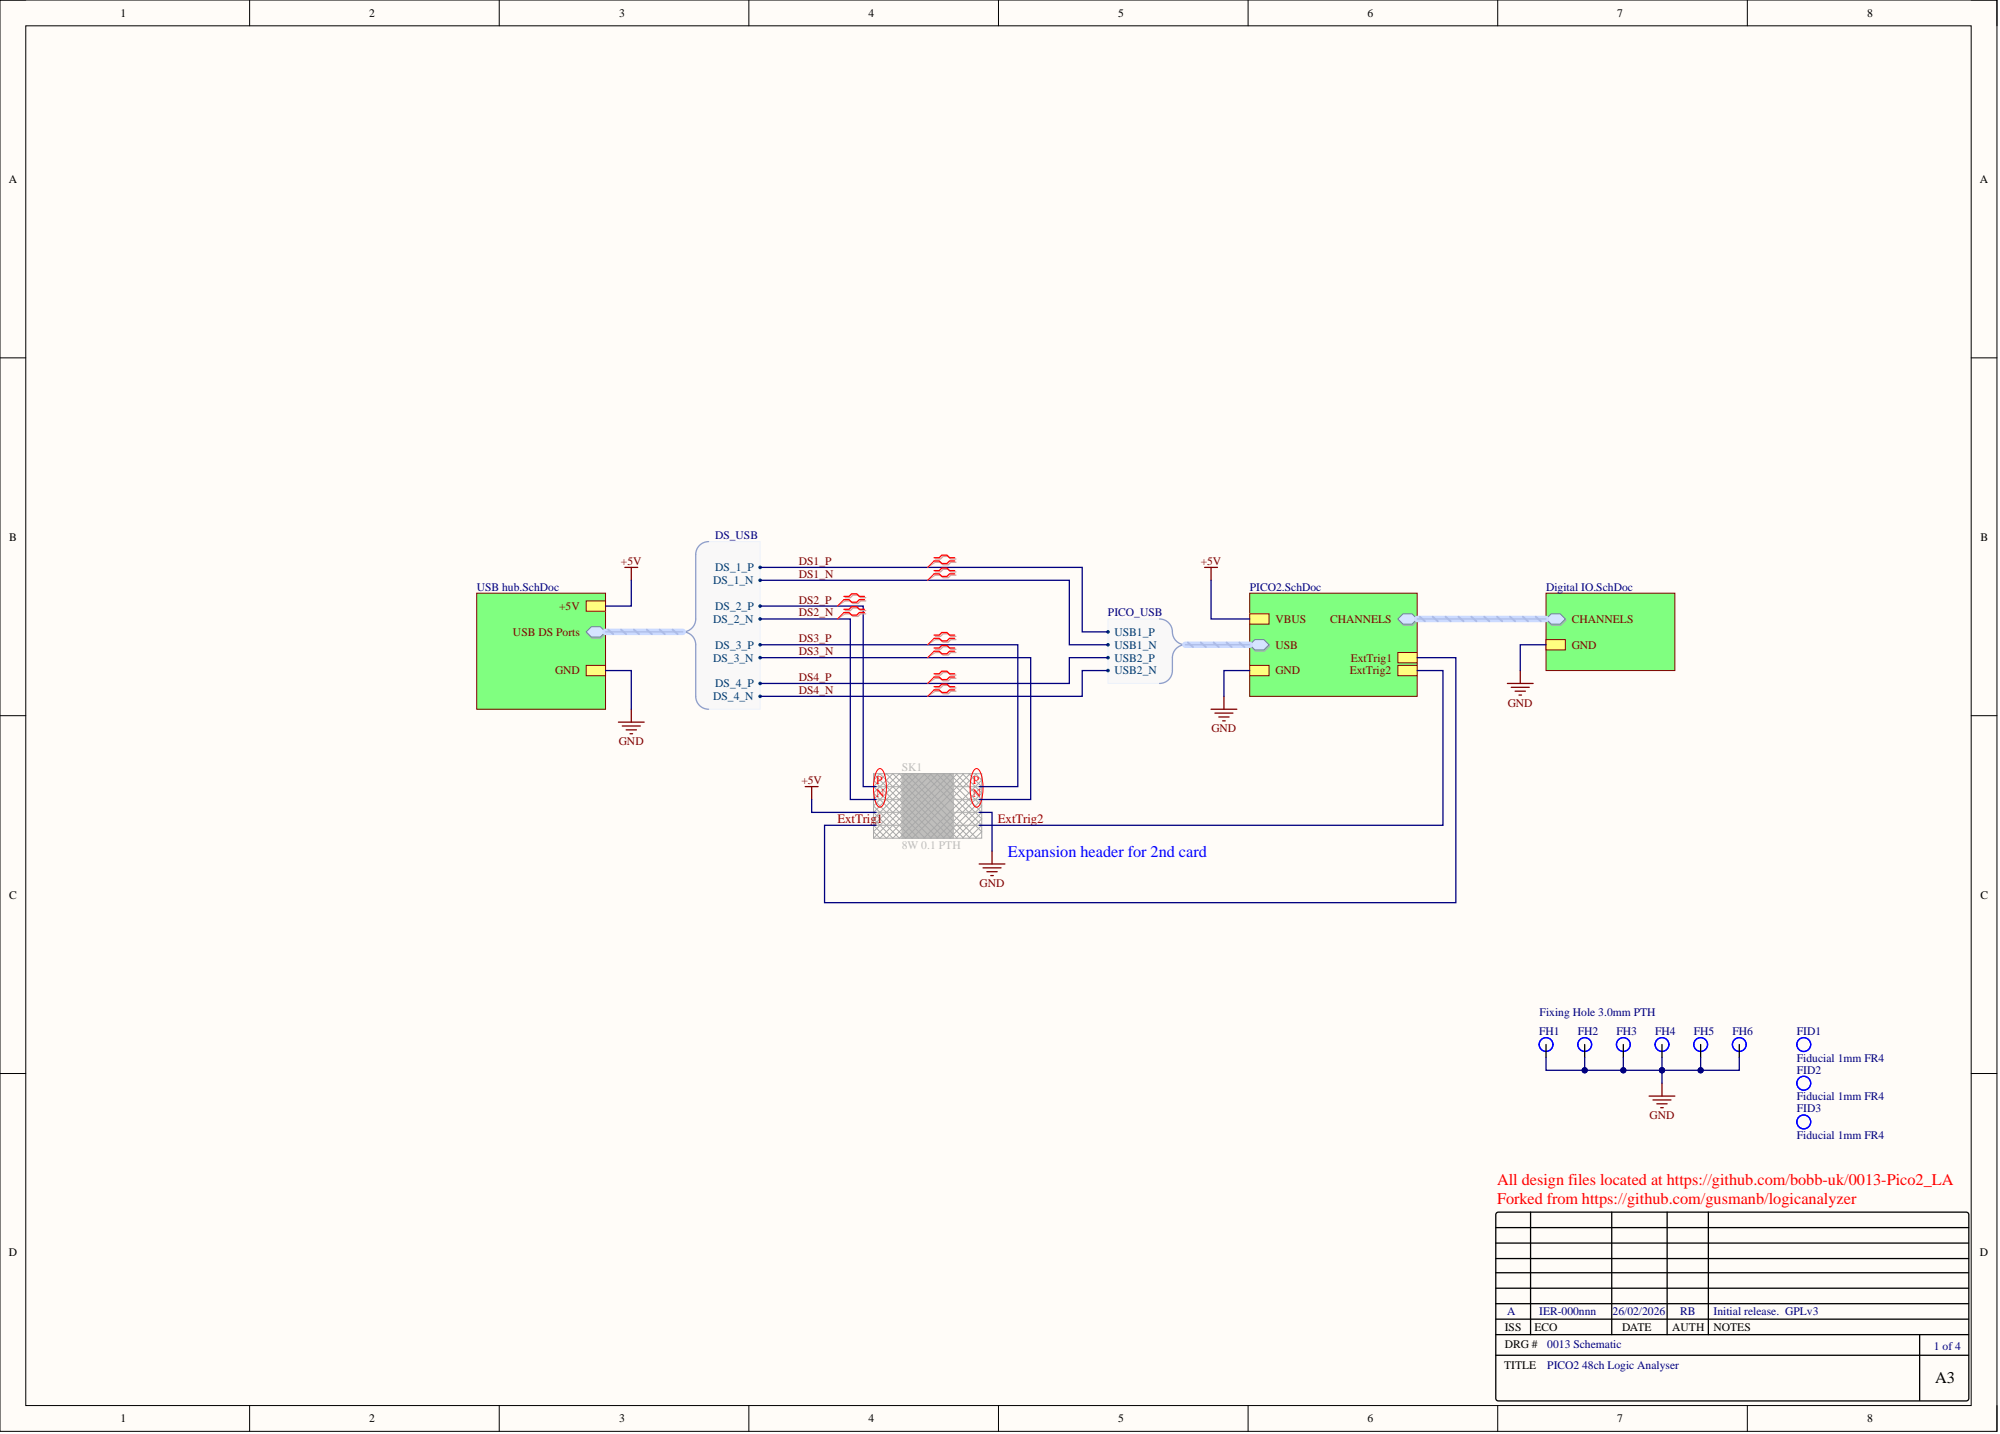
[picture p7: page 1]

DS3_P
DS3_N

DS4_P
DS4_N

SK1
P | 1 2 | P

All design files located at https://github.com/bobb-uk/0013-Pico2_LA
Forked from https://github.com/gusmanb/logicanalyzer

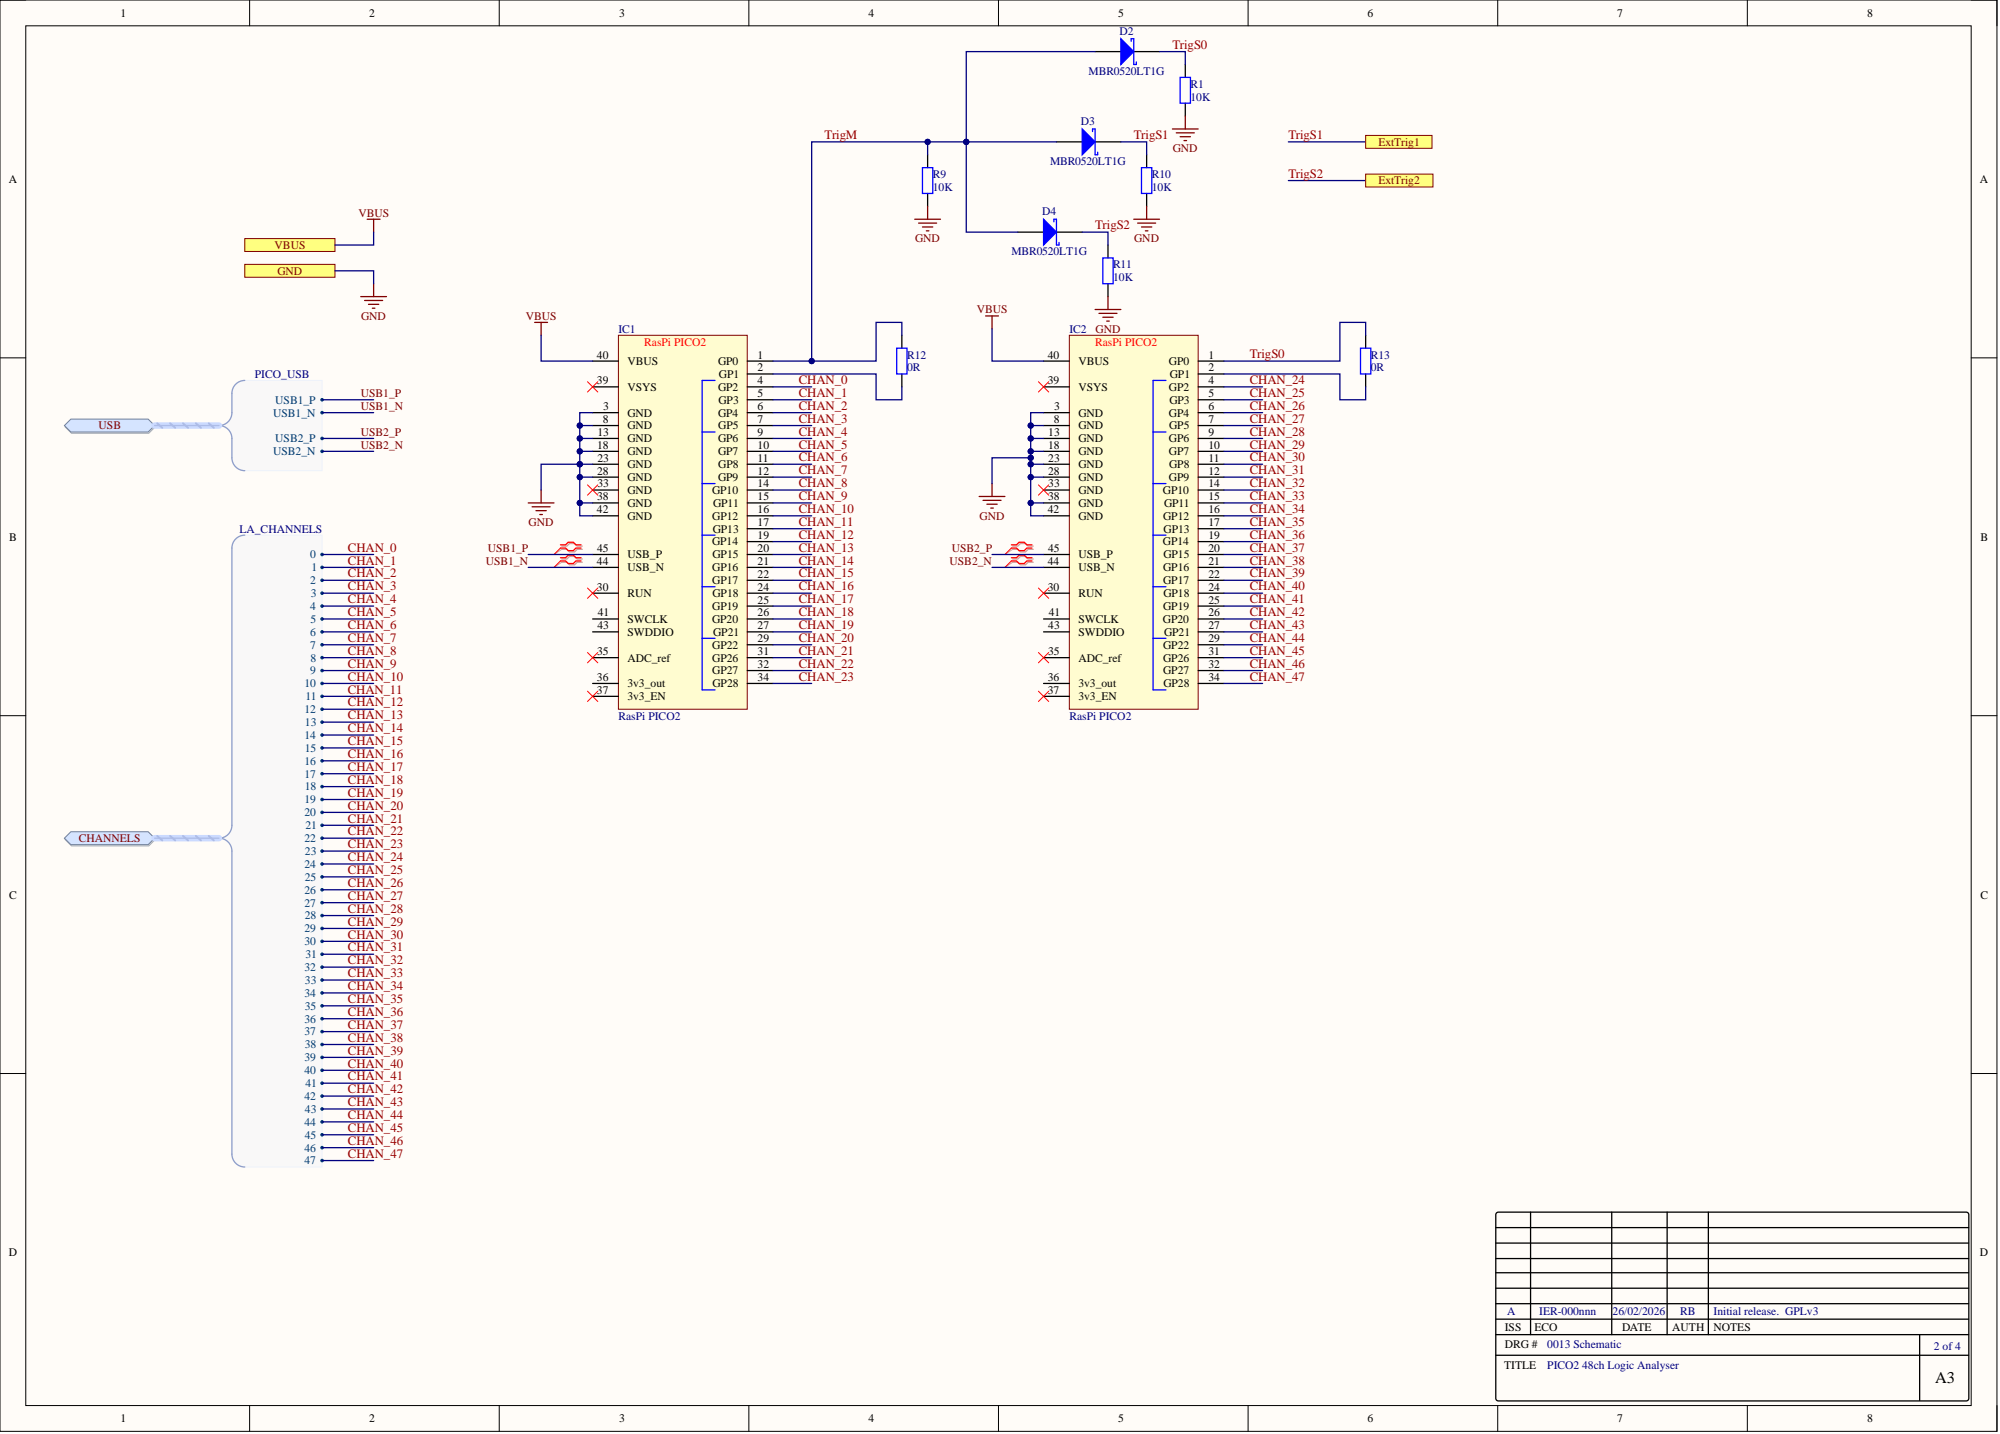
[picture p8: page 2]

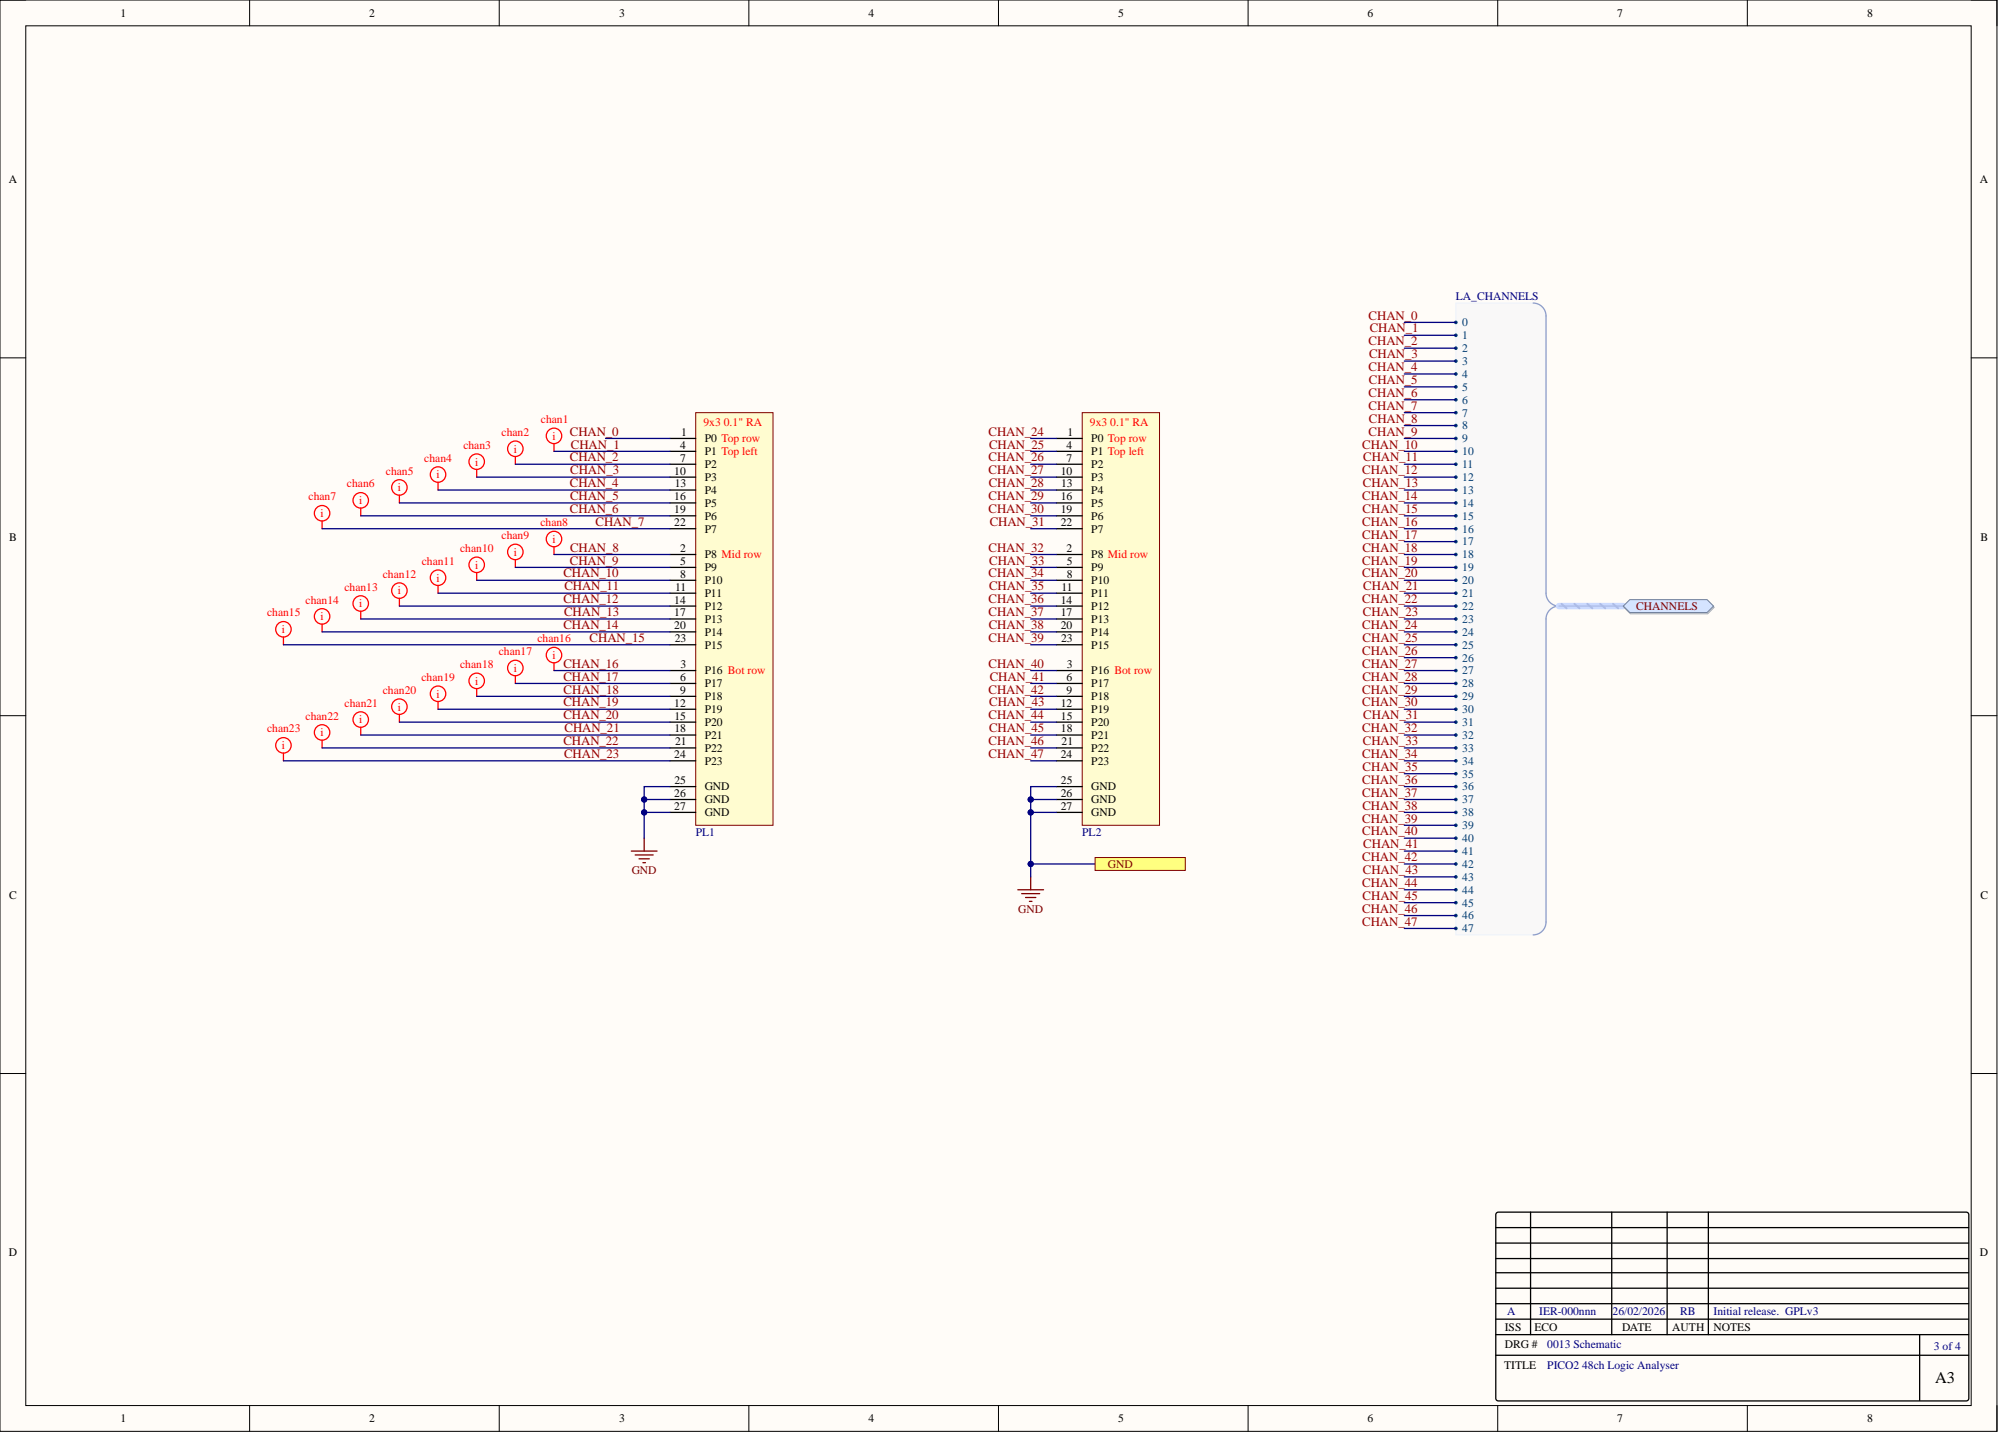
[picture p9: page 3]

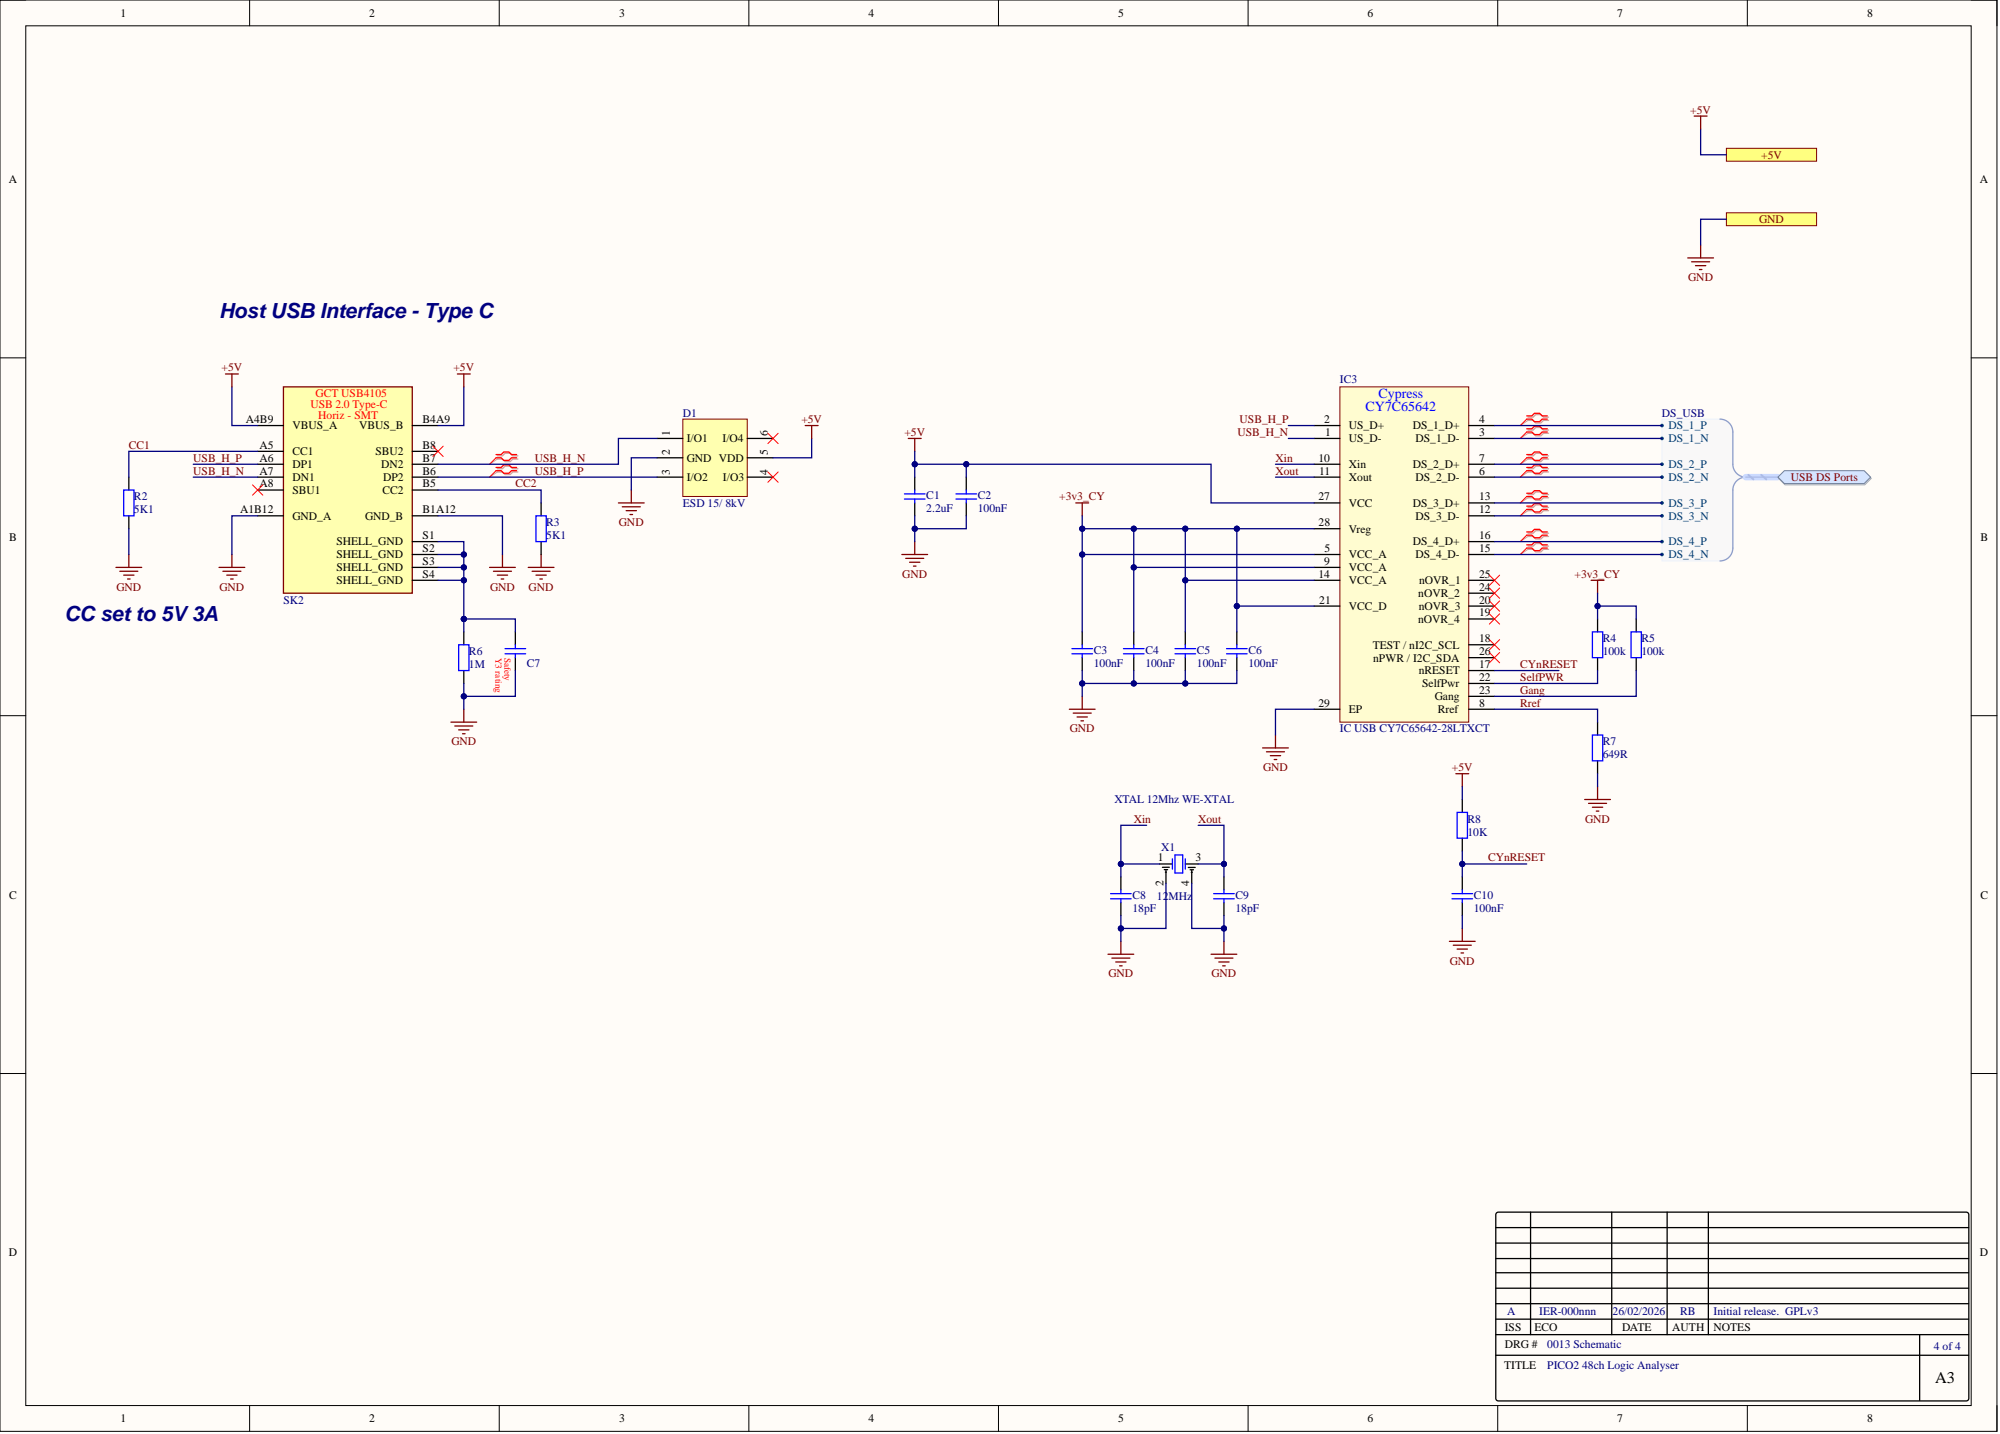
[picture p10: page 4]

Host USB Interface - Type C

VCC 27 Vreg 28
